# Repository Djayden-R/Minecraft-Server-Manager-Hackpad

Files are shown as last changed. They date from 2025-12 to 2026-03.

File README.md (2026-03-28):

# Minecraft Server Manager Hackpad

This is a hackpad designed to control a Minecraft server. It has keys to interact with the server and device: a start key and two keys to switch between modes. It will indicate the state of the server using a status LED and has a screen that displays the live chat and other information about the server.

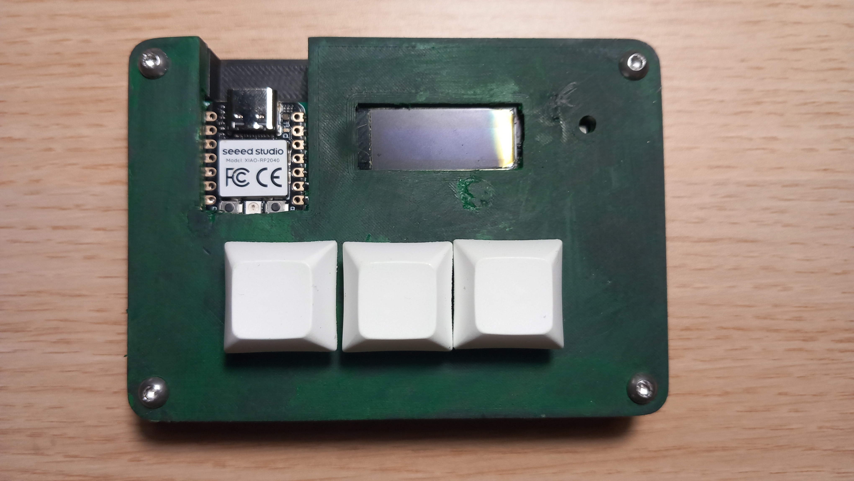
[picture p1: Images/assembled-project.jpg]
Overall Hackpad


A demonstraction video can be found [here](https://youtu.be/SgViQMdPCGE) and the build process is documented [here](https://blueprint.hackclub.com/projects/6261).

## Why did I make it?

I have a Minecraft server with my friends and often don't notice it when my friends are online, so I wanted to make this device to show when my friends go online.

Couldn't I just make a Discord bot to ping me when my friends go online? Yeah, but it wouldn't be as fun as making a special device for on my desk that also shows the Minecraft chat live.

## How does it work?

The main logic of checking the server status and the chat isn't done on the Hackpad itself, but instead on the computer it is connected to. To make this work the pc will need to run the ```host.py```. This is going to connect with Home Assistant via MQTT. There is a Home Assistant automation needed that sends the information to the correct MQTT topics.
The program can send the following to the Hackpad (over USB):

- LED [COLOR]
- STATUS [STATUS] [PLAYERS] [VERSION] [UPTIME]
- CHAT [LAST_MESSAGE]
- LOG [LOGLINE]
- MODE [MODE]

The Hackpads task is to handle displaying text on the LCD, handle the LED and send the button presses (either LONG or SHORT):

- START
- MODE_NEXT
- MODE_PREV

Also, about the LED, the hackpad displays different colors in different situations:

- Server off > Red
- Server booting > Blinking Orange
- Server on > Blue
- People online > Blinking Green

## Hardware

Schematic                               |  PCB                   |   3D model
:--------------------------------------:|:----------------------:|:-------------------------:
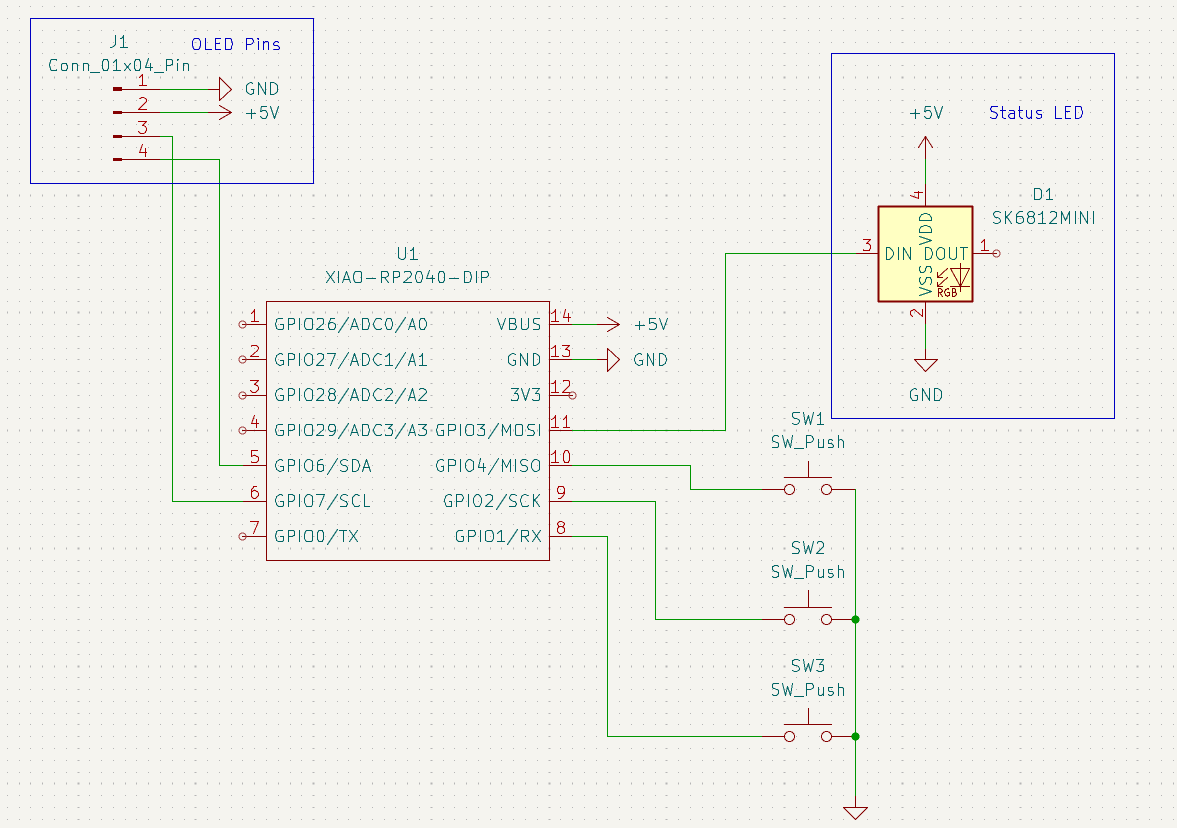
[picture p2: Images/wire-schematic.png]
Schematic
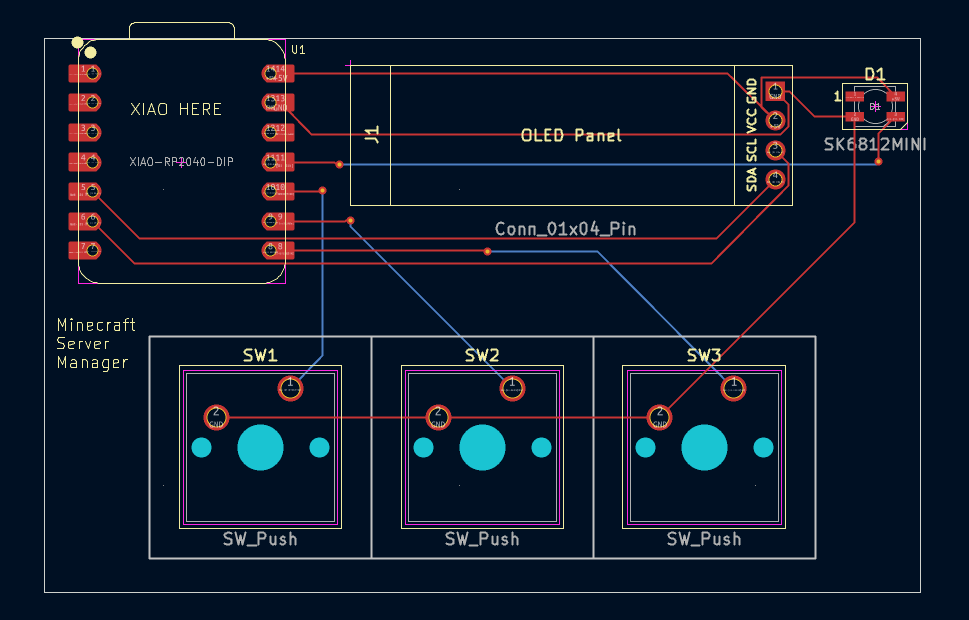
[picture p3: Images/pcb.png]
PCB
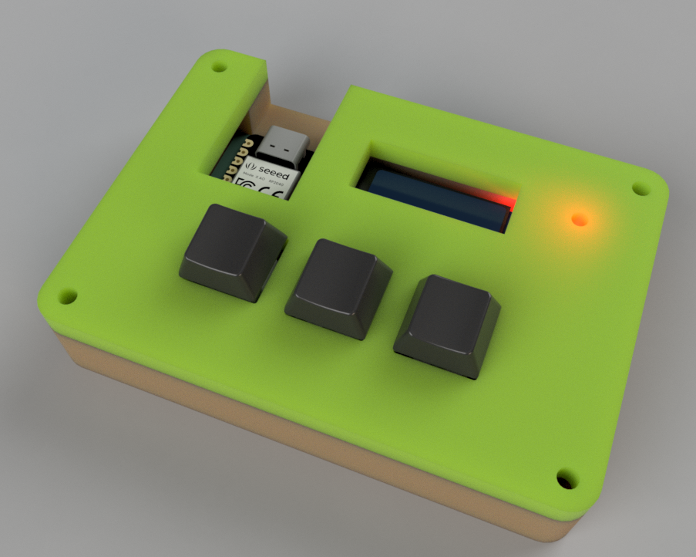
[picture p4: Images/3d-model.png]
Case
 |  | 

## BOM

- 3x Cherry MX Switches
- 3x DSA Keycaps
- 1x SK6812 MINI-E LED
- 1x 0.91" 128x32 OLED Display
- 1x XIAO RP2040
- 1x Case (2 printed parts)

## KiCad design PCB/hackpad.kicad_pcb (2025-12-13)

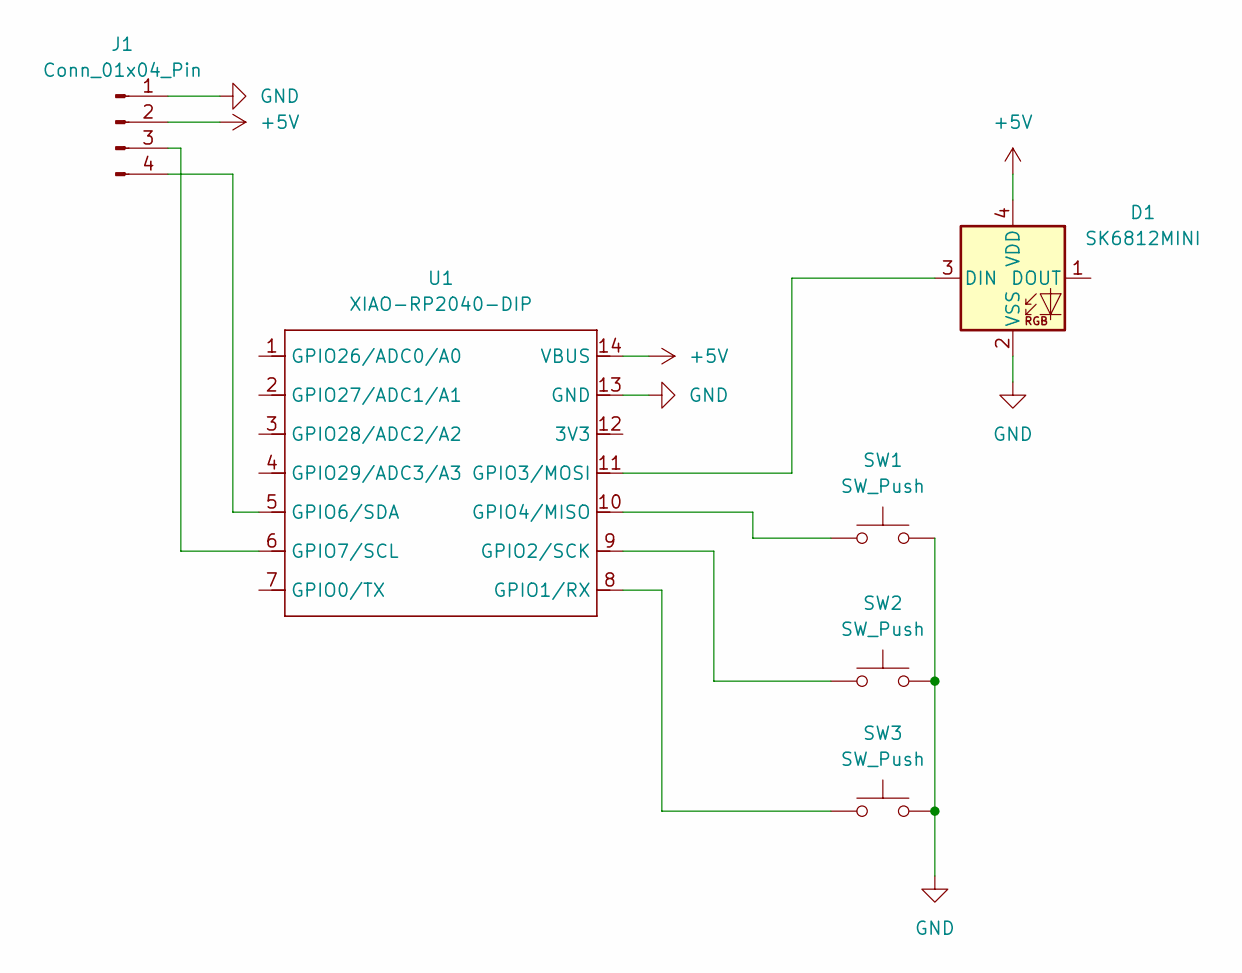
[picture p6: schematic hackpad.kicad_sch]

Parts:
D1: SK6812MINI; LED_SK6812MINI_PLCC4_3.5x3.5mm_P1.75mm
J1: Conn_01x04_Pin; SSD1306-0.91-OLED-4pin-128x32
SW1, SW2, SW3: SW_Push; SW_Cherry_MX_1.00u_PCB
U1: XIAO-RP2040-DIP

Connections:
+5V: D1.4 (VDD), J1.2, U1.14 (VBUS)
GND: D1.2 (VSS), J1.1, SW1.2, SW2.2, SW3.2, U1.13 (GND)
unnamed: D1.3 (DIN), U1.11 (GPIO3/MOSI)
unnamed: J1.3, U1.6 (GPIO7/SCL)
unnamed: J1.4, U1.5 (GPIO6/SDA)
unnamed: SW3.1, U1.8 (GPIO1/RX)
unnamed: SW2.1, U1.9 (GPIO2/SCK)
unnamed: SW1.1, U1.10 (GPIO4/MISO)

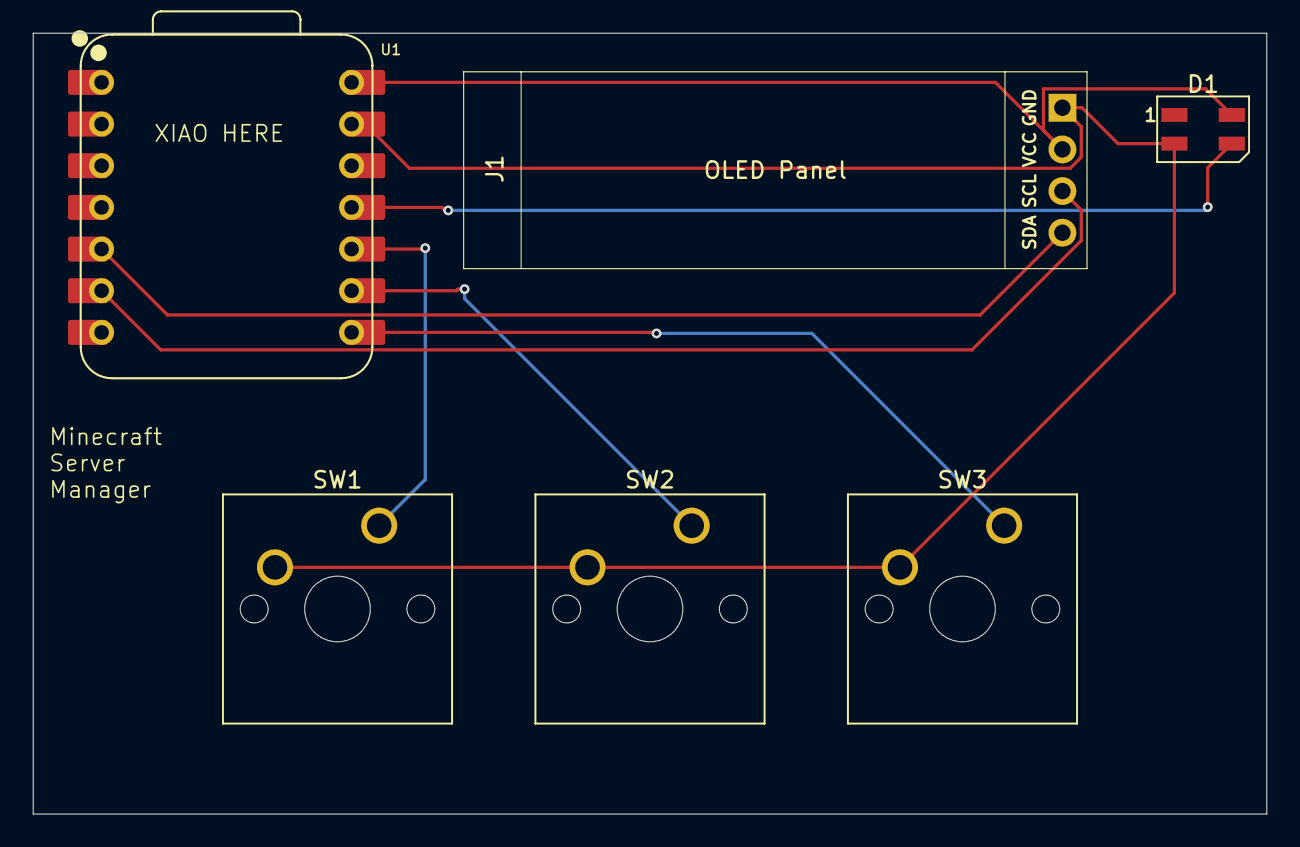
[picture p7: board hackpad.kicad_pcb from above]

Board: 2 copper layers, 75.2 x 47.6 mm, 6 parts (0 on the bottom side), 8 nets.

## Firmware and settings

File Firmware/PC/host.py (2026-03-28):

import serial
from time import sleep, monotonic
import dotenv
import os
from enum import Enum, auto
import paho.mqtt.client as mqtt
import threading
from queue import Queue

SERIAL_EXCEPTION = getattr(serial, "SerialException", None)
if SERIAL_EXCEPTION is None:
    serialutil = getattr(serial, "serialutil", None)
    SERIAL_EXCEPTION = getattr(serialutil, "SerialException", OSError) if serialutil else OSError

SERIAL_EXCEPTION_TYPES = [OSError, AttributeError]
if isinstance(SERIAL_EXCEPTION, type):
    SERIAL_EXCEPTION_TYPES.insert(0, SERIAL_EXCEPTION)
SERIAL_EXCEPTIONS = tuple(SERIAL_EXCEPTION_TYPES)

dotenv.load_dotenv()

#------------ Setup Variables ------------#

# Hackpad port
COM_PORT = "COM5"

# MQTT
MQTT_BROKER = "192.168.1.186"
MQTT_PORT = 1883
MQTT_USERNAME = "mqtt-user"
MQTT_PASSWORD = os.getenv("MQTT_PASSWORD")

#-----------------------------------------#

class ServerState(Enum):
    OFF = auto()
    STARTING = auto()
    RUNNING = auto()
    PEOPLE_ONLINE = auto()


class Mode(Enum):
    STATUS = auto()
    CHAT = auto()
    LOG = auto()

current_mode = Mode.STATUS
state = ServerState.OFF
ser = None
ser_lock = threading.Lock()
server_started_at = None
last_status_sent_at = 0.0
last_led_sent_at = 0.0
led_blink_on = True

server_info = {
    "status": ServerState.OFF,
    "players": 0,
    "version": "unknown",
    "chat_lines": [],
    "log_lines": []
}



# ------------- MQTT Setup ------------- #
MQTT_TOPICS = [
    ("minecraft/chat", 0),
    ("minecraft/log", 0),
    ("minecraft/players", 0),
    ("minecraft/version", 0),
    ("minecraft/server_state", 0),
]

def on_connect(client, userdata, flags, rc):
    if rc == 0:
        print("Connected to MQTT")
        for topic, qos in MQTT_TOPICS:
            client.subscribe(topic, qos)
    else:
        print(f"Connecting to MQTT failed: {rc}")

def sanitize_token(value) -> str:
    text = str(value) if value is not None else "unknown"
    return text.replace(" ", "_")

def format_uptime() -> str:
    if server_started_at is None:
        return "0s"

    seconds = int(monotonic() - server_started_at)
    if seconds < 60:
        return f"{seconds}s"

    minutes, secs = divmod(seconds, 60)
    if minutes < 60:
        return f"{minutes}m{secs}s"

    hours, mins = divmod(minutes, 60)
    return f"{hours}h{mins}m"

def mode_name(mode: Mode) -> str:
    return mode.name

def pretty_status(state_value: ServerState | None) -> str:
    if state_value is None:
        return "Unknown"

    if state_value == ServerState.PEOPLE_ONLINE:
        return "People Online"

    return state_value.name.title()

def set_mode(mode: Mode):
    global current_mode
    current_mode = mode
    send(f"MODE {mode_name(mode)}")

    if mode == Mode.STATUS:
        update_status_display()
    elif mode == Mode.CHAT and server_info["chat_lines"]:
        update_chat_display(server_info["chat_lines"][-1])
    elif mode == Mode.LOG and server_info["log_lines"]:
        update_log_display(server_info["log_lines"][-1])

def update_status_display():
    global last_status_sent_at

    status_name = pretty_status(server_info["status"])

    players = server_info["players"] if server_info["players"] is not None else 0
    version = server_info["version"] if server_info["version"] is not None else "unknown"
    uptime = format_uptime()

    send(
        "STATUS "
        + sanitize_token(status_name)
        + " "
        + sanitize_token(players)
        + " "
        + sanitize_token(version)
        + " "
        + sanitize_token(uptime)
    )
    last_status_sent_at = monotonic()

def update_chat_display(new_line: str):
    send("CHAT " + new_line)

def update_log_display(new_line: str):
    send("LOG " + new_line)

def current_server_state() -> ServerState:
    status = server_info["status"]
    if isinstance(status, ServerState):
        return status
    return ServerState.OFF

def update_led(force: bool = False):
    global last_led_sent_at, led_blink_on

    now = monotonic()
    state_value = current_server_state()

    # Blink while booting or when players are online.
    should_blink = state_value in (ServerState.STARTING, ServerState.PEOPLE_ONLINE)
    interval = 0.5 if should_blink else 1.0

    if not force and (now - last_led_sent_at) < interval:
        return

    if should_blink:
        led_blink_on = not led_blink_on
    else:
        led_blink_on = True

    if state_value == ServerState.OFF:
        color = (48, 0, 0)  # red
    elif state_value == ServerState.STARTING:
        color = (255, 110, 0) if led_blink_on else (0, 0, 0)  # amber blink
    elif state_value == ServerState.RUNNING:
        color = (0, 40, 120)  # blue
    else:
        color = (0, 180, 0) if led_blink_on else (0, 20, 0)  # green pulse

    send(f"LED {color[0]} {color[1]} {color[2]}")
    last_led_sent_at = now

def on_message(client, userdata, msg):
    global server_started_at

    payload = msg.payload.decode("utf-8", errors="ignore")
    print(f"[MQTT EVENT] {msg.topic}: {payload}")

    if msg.topic == "minecraft/players": # Update playercount and server state
        player_amount = payload
        if player_amount.isdigit():
            if int(player_amount) == 0:
                server_info["status"] = ServerState.RUNNING
            elif int(player_amount) > 0:
                server_info["status"] = ServerState.PEOPLE_ONLINE
            server_info["players"] = int(player_amount)
            if server_started_at is None:
                server_started_at = monotonic()
        elif player_amount == "unavailable":
            server_info["status"] = ServerState.OFF
            server_info["players"] = 0
            server_started_at = None

        update_status_display()
        update_led(force=True)

    elif msg.topic == "minecraft/log": # Check if mode is log and draw log line to screen
        log_message = payload
        server_info["log_lines"].append(log_message)
        update_log_display(log_message)

    elif msg.topic == "minecraft/chat":
        chat_message = payload
        server_info["chat_lines"].append(chat_message)
        update_chat_display(chat_message)

    elif msg.topic == "minecraft/version":
        version_number = payload
        if version_number != "unavailable":
            if version_number != server_info["version"]:
                server_info["version"] = version_number
            update_status_display()
        else:
            server_info["version"] = "unknown"
            update_status_display()
    elif msg.topic == "minecraft/server_state":
        state_text = payload.strip().lower()

        if state_text in ("off", "offline", "unavailable", "stopped"):
            server_info["status"] = ServerState.OFF
            server_info["players"] = 0
            server_started_at = None
        elif state_text in ("booting", "starting", "startup"):
            server_info["status"] = ServerState.STARTING
            if server_started_at is None:
                server_started_at = monotonic()
        elif state_text in ("running", "online", "on"):
            server_info["status"] = ServerState.RUNNING
            if server_started_at is None:
                server_started_at = monotonic()

        update_status_display()
        update_led(force=True)

client = mqtt.Client()

client.username_pw_set(
    username=MQTT_USERNAME,
    password=MQTT_PASSWORD
)

client.on_connect = on_connect
client.on_message = on_message

client.connect(MQTT_BROKER, MQTT_PORT, keepalive=60)
client.loop_start()

# ------------------------------------- #

def send(cmd: str):
    if ser is None:
        return

    with ser_lock:
        ser.write((cmd + "\n").encode())

def read():
    if ser is None:
        return None

    if ser.in_waiting:
        return ser.readline().decode(errors="ignore").strip()
    return None

def start_minecraft_server():
    global state
    client.publish("minecraft/start_server", "press")
    state = ServerState.STARTING
    server_info["status"] = ServerState.STARTING
    update_status_display()
    update_led(force=True)
    print("Minecraft server started")

def cycle_mode(direction: int):
    modes = [Mode.STATUS, Mode.CHAT, Mode.LOG]
    idx = modes.index(current_mode)
    next_idx = (idx + direction) % len(modes)
    set_mode(modes[next_idx])

def BUTTON_handler(data: str):
    data_parts = data.split(" ")
    button = data_parts[0] if len(data_parts) > 0 else ""
    press_type = data_parts[1] if len(data_parts) > 1 else ""

    print(f"Button {button} was {press_type} pressed")

    if press_type == "SHORT":
        if button == "NEXT":
            cycle_mode(1)
        elif button == "PREV":
            cycle_mode(-1)
        elif button == "START":
            set_mode(Mode.STATUS)

    if button == "START" and press_type == "LONG":
        print("Starting Minecraft server via Home Assistant")
        start_minecraft_server()
        

def ERR_handler(data: str):
    if data:
        parts = data.split(":", 1)
        error_type = parts[0]
        error_info = parts[1] if len(parts) > 1 else ""
        print(f"{error_type} Error: {error_info}")
    else:
        print("Unknown ERR message")

def STATUS_handler(data: str):
    parts = data.split(" ", 1)
    status_type = parts[0] if len(parts) > 0 else ""
    status_value = parts[1] if len(parts) > 1 else ""

    if status_type == "MODE" and status_value:
        print(f"Device mode set to {status_value}")
    elif status_type == "READY":
        print("Device is ready")
    elif data:
        print(f"STATUS {data}")
    else:
        print("Unknown STATUS message")

def process_msg(msg: str):
    parts = msg.split(" ", 1)
    command_type = parts[0]
    data = parts[1] if len(parts) > 1 else ""

    command_handlers = {
        "BUTTON": BUTTON_handler,
        "ERR": ERR_handler,
        "STATUS": STATUS_handler,
    }
    
    if command_type in command_handlers:
        command_handlers[command_type](data)
    else:
        print("Unrecognized message: ", msg)

def wait_for_device_ready():
    send("START")
    retries = 100
    while retries > 0:
        msg = read()
        if msg:
            parts = msg.split(" ", 1)
            command_type = parts[0]
            if command_type == "STATUS" and len(parts) > 1 and parts[1] == "READY":
                return True
            
            print("Waiting for Hackpad... Received: ", msg)
                
        retries -= 1
        sleep(0.1)
    return False

def wait_for_device_connected():
    global ser
    while True:
        try:
            ser = serial.Serial(COM_PORT, 115200, timeout=0)
            print("Found Hackpad on", COM_PORT)
            return
        except SERIAL_EXCEPTIONS:
            sleep(1)

def input_thread(input_queue):
    """Read user input in a separate thread"""
    while True:
        try:
            user_input = input("Send command: ").strip()
            if user_input:
                input_queue.put(user_input)
        except EOFError:
            break

def main():
    wait_for_device_connected()

    if not wait_for_device_ready():
        print("Hackpad not ready, exiting...")
        return
    
    print("Hackpad ready")
    set_mode(Mode.STATUS)
    update_status_display()
    update_led(force=True)
    
    # Start input thread
    input_queue = Queue()
    thread = threading.Thread(target=input_thread, args=(input_queue,), daemon=True)
    thread.start()
    
    while True:
        now = monotonic()
        msg = read()
        if msg:
            process_msg(msg)

        # Keep uptime live on the OLED even when no MQTT events are arriving.
        if server_info["status"] in (ServerState.RUNNING, ServerState.PEOPLE_ONLINE):
            if now - last_status_sent_at >= 1.0:
                update_status_display()

        update_led()

        # Check if there's user input without blocking
        if not input_queue.empty():
            user_input = input_queue.get()
            send(user_input)

        sleep(0.05)

if __name__ == "__main__":
    main()

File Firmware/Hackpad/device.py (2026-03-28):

import sys
import select
from machine import Pin, SoftI2C
from time import sleep, ticks_ms
import ssd1306
from neopixel import NeoPixel

#------------ Connected components ------------#
rgb_led = NeoPixel(Pin(3), 1)

next_button = Pin(1, Pin.IN, Pin.PULL_UP) 
prev_button  = Pin(2, Pin.IN, Pin.PULL_UP)
start_button  = Pin(4, Pin.IN, Pin.PULL_UP)

i2c = None
lcd_display = None
#---------------------------------------------#

button_states = {
    "NEXT": False,
    "PREV": False,
    "START": False,
}

button_press_times = {
    "NEXT": 0,
    "PREV": 0,
    "START": 0,
}

MODE_STATUS = "STATUS"
MODE_CHAT = "CHAT"
MODE_LOG = "LOG"

current_mode = MODE_STATUS

latest_status = {
    "status": "UNKNOWN",
    "players": "0",
    "version": "N/A",
    "uptime": "0s",
}

chat_lines = []
log_lines = []

last_status = None

def send(msg: str):
    sys.stdout.write(msg + "\n")
    flush = getattr(sys.stdout, "flush", None)
    if flush is not None:
        try:
            flush()
        except OSError:
            pass

def init_display():
    bus = SoftI2C(sda=Pin(6), scl=Pin(7), freq=100000)
    addresses = bus.scan()

    if not addresses:
        send("ERR OLED_NOT_FOUND: no I2C devices detected")
        return bus, None

    oled_addr = None
    for candidate in (0x3C, 0x3D):
        if candidate in addresses:
            oled_addr = candidate
            break

    if oled_addr is None:
        oled_addr = addresses[0]

    try:
        display = ssd1306.SSD1306_I2C(128, 32, bus, addr=oled_addr)
        return bus, display
    except OSError as exc:
        send("ERR OLED_INIT_FAILED: " + str(exc))
        return bus, None

def chunk_list(lst, n):
    """Yield successive n-sized chunks from lst."""
    for i in range(0, len(lst), n):
        yield lst[i:i + n]

def read_line():
    # Create a poll object to check if stdin has data available
    poll_obj = select.poll()
    poll_obj.register(sys.stdin, select.POLLIN)
    
    # Check if data is available (0ms timeout = non-blocking)
    if poll_obj.poll(0):
        try:
            line = sys.stdin.readline()
            if line:
                return line.strip()
        except:
            pass
    return None

def trim_display_text(text: str, width: int = 21) -> str:
    if len(text) <= width:
        return text
    return text[:width]

def prettify_status_name(status: str) -> str:
    if not status:
        return "Unknown"

    return status.replace("_", " ").title()

def push_line(buffer, text: str, max_lines: int = 3):
    buffer.append(text)
    if len(buffer) > max_lines:
        del buffer[0]

def render_status():
    if lcd_display is None:
        return

    lcd_display.fill(0)
    pretty_status = prettify_status_name(latest_status["status"])

    lcd_display.text("Server", 0, 0)
    lcd_display.text(trim_display_text(pretty_status), 0, 8)
    lcd_display.text(trim_display_text("Players: " + latest_status["players"]), 0, 16)
    lcd_display.text(trim_display_text("U:" + latest_status["uptime"]), 0, 24)
    lcd_display.show()

def render_lines(title: str, lines):
    if lcd_display is None:
        return

    lcd_display.fill(0)
    lcd_display.text(title, 0, 0)

    visible = lines[-3:]
    y = 8
    for line in visible:
        lcd_display.text(trim_display_text(line), 0, y)
        y += 8

    lcd_display.show()

def render_current_mode():
    if current_mode == MODE_STATUS:
        render_status()
    elif current_mode == MODE_CHAT:
        render_lines("Chat", chat_lines)
    elif current_mode == MODE_LOG:
        render_lines("Log", log_lines)

def handle_led(data: str):
    # Expecting format: "RRGGBB" (hexadecimal)
    data_parts = data.split()
    if len(data_parts) == 3:
        try:
            r, g, b = data_parts[0:3]
            rgb_led[0] = (int(r), int(g), int(b))
            rgb_led.write()
        except ValueError:
            send("ERR INVALID_LED_CMD: RGB values must be integers")
    elif len(data_parts) == 1:
        if len(data_parts[0]) == 6:
            try:
                r, g, b = list(chunk_list(data_parts[0], 2))
                rgb_led[0] = (int(r, 16), int(g, 16), int(b, 16))
                rgb_led.write()
            except ValueError:
                send("ERR INVALID_LED_CMD: invalid hex color")
        else:
            send("ERR INVALID_LED_CMD: expected 6-char hex color")
    else:
        send(f"ERR INVALID_LED_CMD: {len(data_parts)} arguments")

def handle_status(data: str):
    global last_status
    parts = data.split()
    if len(parts) != 4:
        send(f"ERR INVALID_STATUS_CMD: should contain 4 arguments (contains {len(parts)})")
        return

    status, player_count, version_number, uptime = parts

    if parts != last_status:
        latest_status["status"] = status
        latest_status["players"] = player_count
        latest_status["version"] = version_number
        latest_status["uptime"] = uptime

        if current_mode == MODE_STATUS:
            render_status()

        last_status = parts

def handle_chat(data: str):
    message = data.strip()
    if not message:
        send("ERR INVALID_CHAT_CMD: missing message")
        return

    push_line(chat_lines, message)
    if current_mode == MODE_CHAT:
        render_lines("Chat", chat_lines)

def handle_log(data: str):
    message = data.strip()
    if not message:
        send("ERR INVALID_LOG_CMD: missing message")
        return

    push_line(log_lines, message)
    if current_mode == MODE_LOG:
        render_lines("Log", log_lines)

def handle_mode(data: str):
    global current_mode

    mode = data.strip().upper()
    if mode not in (MODE_STATUS, MODE_CHAT, MODE_LOG):
        send("ERR INVALID_MODE_CMD: expected STATUS|CHAT|LOG")
        return

    current_mode = mode
    render_current_mode()
    send("STATUS MODE " + mode)
    
def handle_start(data: str):
    send("STATUS READY")

def process_command(cmd: str):
    parts = cmd.split(" ", 1)
    command_type = parts[0]
    data = parts[1] if len(parts) > 1 else ""

    command_handlers = {
        "LED": handle_led,
        "START": handle_start,
        "STATUS": handle_status,
        "CHAT": handle_chat,
        "LOG": handle_log,
        "MODE": handle_mode,
    }

    if command_type in command_handlers:
        command_handlers[command_type](data)
    else:
        send("ERR UNKNOWN_CMD: " + command_type)

def check_button(button: Pin, name: str):
    was_pressed = button_states[name]
    is_pressed = not button.value()

    changed_to_pressed = is_pressed and not was_pressed
    changed_to_released = not is_pressed and was_pressed

    if changed_to_pressed:
        button_states[name] = True
        button_press_times[name] = ticks_ms()

    elif changed_to_released:
        button_states[name] = False
        press_duration = ticks_ms() - button_press_times[name]

        if press_duration > 400:
            print("BUTTON " + name + " LONG")
        else:
            print("BUTTON " + name + " SHORT")
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

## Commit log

2025-12-13 add pcb and 3d model
    [hackpad.kicad_pcb, hackpad.kicad_sch]
2025-12-13 add all libraries for KiCad
2025-12-21 make device.py
2025-12-21 add wait until device connected
2025-12-22 move PC code to its own folder and replace Home Assistant API with MQTT
    [host.py]
2025-12-23 change location of Hacpad folder and add lcd and led to device.py
2026-03-28 refactor device.py and host.py for improved functionality and structure
